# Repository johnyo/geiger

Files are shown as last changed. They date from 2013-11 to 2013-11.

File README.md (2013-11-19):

geiger
======

Low Voltage 2.5V PIN Diode Based Geiger Counter

Purpose
======

Super low voltgae Geiger Counter using a modified PIN photodiode. See Bernd Laquai's paper on the subject here: http://www.opengeiger.de/ABGDetektor_en.pdf. The first stage charge amplifier gain is set by the feedback Cap and Resistor. Bigger resistor = more gain, but it pulls the output low and reduces the amplifier's swing on the negative side. 1M is about the biggest resistor you can safely use. The second stage amp takes the negative pulse from the 1st stage and inverts it and boost it x10 so it can be easily read.

Project Structure
=================

/GeigerCounter
* The Eagle PCB project

/Library
* Any components that are not found in the Eagle or SparkFun default libraries, I have made myself and they are here.

/GeigerCounter/FabricationOutput
* This holds the fabrication output script. Based on SparkFun's script. It also holds the zip file Gerber files that were sent out for fabrication.

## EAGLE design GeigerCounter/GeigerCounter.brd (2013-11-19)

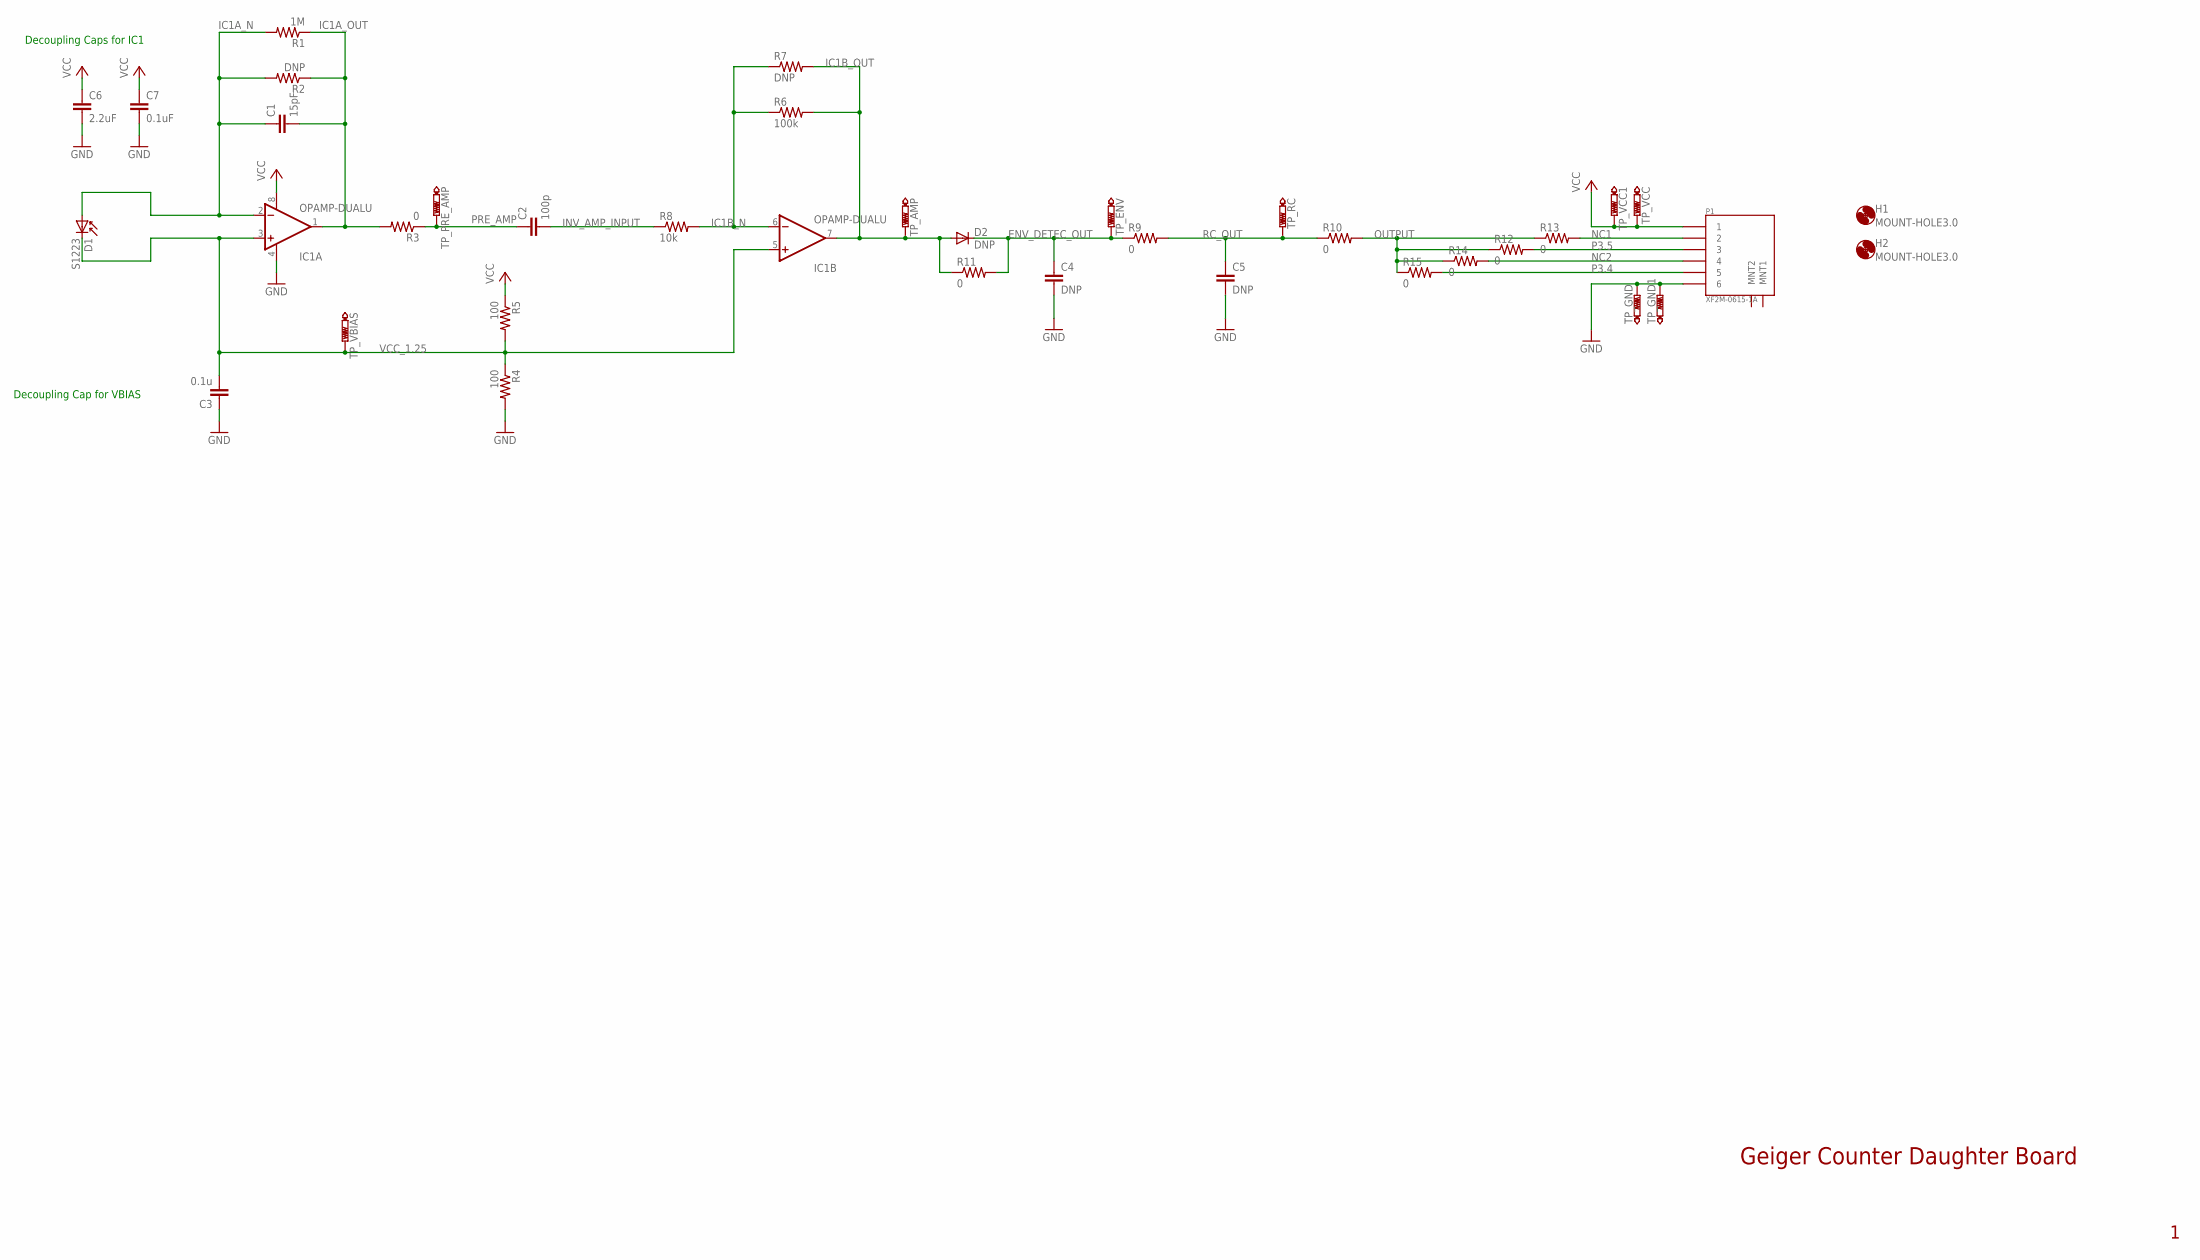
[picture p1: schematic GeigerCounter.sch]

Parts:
C1: 15pF; 0603-CAP
C2: 100p; 0603-CAP
C3: 0.1u; 0603-CAP
C4, C5: DNP; 0603-CAP
C6: 2.2uF; 0603-CAP
C7: 0.1uF; 0603-CAP
D1: S1223; DIODE-1N4001
D2: DNP; SOT23-3
H1, H2: MOUNT-HOLE3.0; 3,0
IC1: OPAMP-DUALU; SO08
P1: XF2M-0615-1A
R1: 1M; 0603-RES
R2, R7: DNP; 0603-RES
R3, R9, R10, R11, R12, R13, R14, R15: 0; 0603-RES
R4, R5: 100; 0603-RES
R6: 100k; 0603-RES
R8: 10k; 0603-RES
TP_AMP: PTR1PAD1-20; P1-20
TP_ENV: PTR1PAD1-20; P1-20
TP_GND, TP_GND1: PTR1PAD1-20; P1-20
TP_PRE_AMP: PTR1PAD1-20; P1-20
TP_RC: PTR1PAD1-20; P1-20
TP_VBIAS: PTR1PAD1-20; P1-20
TP_VCC, TP_VCC1: PTR1PAD1-20; P1-20

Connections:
ENV_DETEC_OUT: C4.1, D2.3 (C), R9.1, R11.2, TP_ENV.TP
GND: C3.1, C4.2, C5.2, C6.2, C7.2, IC1.4 (V-), P1.6, R4.2, TP_GND.TP, TP_GND1.TP
IC1A_N: C1.1, D1.A, IC1.2 (-IN), R1.2, R2.2
IC1A_OUT: C1.2, IC1.1 (OUT), R1.1, R2.1, R3.2
IC1B_N: IC1.6 (-IN), R6.1, R7.1, R8.2
IC1B_OUT: D2.1 (A), IC1.7 (OUT), R6.2, R7.2, R11.1, TP_AMP.TP
INV_AMP_INPUT: C2.2, R8.1
NC1: P1.2, R13.2
NC2: P1.4, R14.2
OUTPUT: R10.2, R12.1, R13.1, R14.1, R15.1
P3.4: P1.5, R15.2
P3.5: P1.3, R12.2
PRE_AMP: C2.1, R3.1, TP_PRE_AMP.TP
RC_OUT: C5.1, R9.2, R10.1, TP_RC.TP
VCC: C6.1, C7.1, IC1.8 (V+), P1.1, R5.1, TP_VCC.TP, TP_VCC1.TP
VCC_1.25: C3.2, D1.C, IC1.3 (+IN), IC1.5 (+IN), R4.1, R5.2, TP_VBIAS.TP

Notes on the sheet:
Decoupling Caps for IC1
Decoupling Cap for VBIAS
Geiger Counter Daughter Board

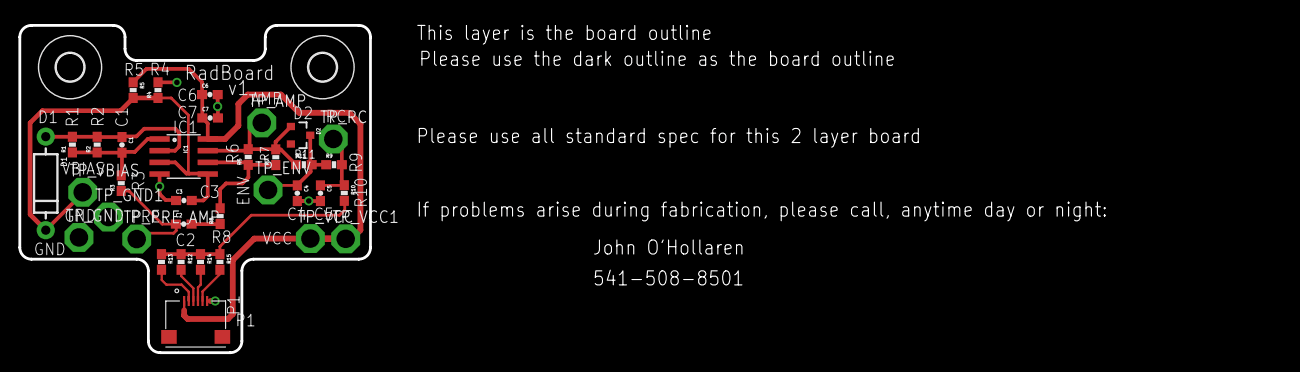
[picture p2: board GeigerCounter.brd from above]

Board: 2 copper layers, 38.1 x 35.6 mm, 37 parts (0 on the bottom side), 16 nets.

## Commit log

2013-10-19 initial commit, empty project
    [GeigerCounter.brd, GeigerCounter.sch]
2013-10-19 Added components and libraries that will be used in the project. I am using a generic op amp footprint, but made a custom photodiode footprint. I am using through hole caps and resistors throughout.
    [GeigerCounter.brd, GeigerCounter.sch]
2013-10-19 Added a new library part for the connector I will be using.
    [GeigerCounter.brd, GeigerCounter.sch]
2013-10-19 Fixed naming error with connector schematic, it was tValue/tName instead of Value/Name
    [GeigerCounter.brd, GeigerCounter.sch]
2013-10-19 preliminary schematic work
    [GeigerCounter.brd, GeigerCounter.sch]
2013-10-19 all components placed in schematic
    [GeigerCounter.brd, GeigerCounter.sch]
2013-10-23 Added header pins as well as cleaned up schematic a bit. Also added test points
    [GeigerCounter.brd, GeigerCounter.sch]
2013-10-23 Added the Bill of Materials
    [BOM.xlsx]
2013-10-23 Updated with new connector on output
    [GeigerCounter.brd, GeigerCounter.sch]
2013-10-25 Revised schematic based on working breadboard. Changed footprints to SMD pads.
    [GeigerCounter.brd, GeigerCounter.sch]
2013-10-25 Removed BOM
    [BOM.xlsx]
2013-10-25 Layout completed. Routed not yet started.
    [GeigerCounter.brd, GeigerCounter.sch]
2013-10-25 Basic routing completed. No pours yet.
    [GeigerCounter.brd, GeigerCounter.sch]
2013-10-25 More routing
    [GeigerCounter.brd, GeigerCounter.sch]
2013-10-25 Beginning to debug errors. Have not poured ground pour yet.
    [GeigerCounter.brd, GeigerCounter.sch]
2013-10-25 All errors from DRC/ERC cleared... need to double check board now
    [GeigerCounter.brd]
2013-10-25 all errors cleared except Stop Mask errors that I think I will ignore
    [GeigerCounter.brd]
2013-10-25 Added silkscreen
    [GeigerCounter.brd, GeigerCounter.sch]
2013-10-25 All unrouted nets now routed
    [GeigerCounter.brd]
2013-10-25 Updated OutJob. This is the version that I sent to FreeDRM
    [GeigerCounter.brd]
2013-11-19 Changed the feedback resistor for the first stage amplifier to be 1M instead of 10M. At 10M it was pulling the output low.
    [GeigerCounter.brd, GeigerCounter.sch]

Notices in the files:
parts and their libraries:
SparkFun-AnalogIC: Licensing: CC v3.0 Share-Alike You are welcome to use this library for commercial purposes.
